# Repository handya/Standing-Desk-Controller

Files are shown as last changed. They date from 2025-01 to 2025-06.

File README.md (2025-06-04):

# Standing Desk Controller (macOS + Arduino)

This repo contains a **macOS test app** and matching **Arduino firmware** to control a custom-built standing desk using serial communication.

Watch the video (https://www.youtube.com/watch?v=RGp0JSYM98Q)

[Find out more on YeahNahDIY.com](https://yeahnahdiy.com/blog/this-standing-desk-was-dumb-so-i-upgraded-it)

⚠️ **This project is experimental and not production ready.** The code is rough and intended for testing purposes only.

---

## 🔌 Arduino Firmware

This firmware runs on an Arduino-compatible board to control the physical desk hardware (motor driver, buttons, rotary encoder).

### Features

* Manual buttons for up/down
* Rotary encoder for height tracking
* 3 preset memory buttons
* EEPROM save/restore of height
* Serial interface for remote commands and status
* Homing support
* Movement timeouts

### Pin Mapping

| Function | Pin |
| --- | --- |
| Rotary A | D3  |
| Rotary B | D2  |
| Button: Down | D4  |
| Button: Up | D5  |
| Button: A | D8  |
| Button: B | D7  |
| Button: C | D6  |
| Motor: Down  | D11 |
| Motor: Up | D12 |

### Serial Protocol (Same as macOS)

* Send `a`, `b`, `c` to go to presets
* Send `s` to stop
* Send a number like `950` to go to that height in mm
* Desk replies with state + height every cycle, e.g.:

  ```
  movingUp
  850
  ```

### Notes

* EEPROM is used to persist height between restarts
* Desk must be **homed** (manually or via `a`/`HOME` button) for presets to work
* Height is calculated using encoder steps with a conversion factor (`heightOffset`)
* All output is in mm

---

## 🛠 Requirements

* Arduino-compatible board (Uno, Nano, etc.)
* Motor driver circuitry
* Rotary encoder (TWO03 latch mode)
* Desk with UP/DOWN inputs
* macOS app built via Xcode
* USB serial connection

---

## 💻 macOS App

### Features

* Control your desk height via a slider
* Three preset position buttons (`a`, `b`, `c`)
* Realtime desk state and height display
* Serial communication via [ORSSerialPort](https://github.com/armadsen/ORSSerialPort)

### Setup

1. Open the project in Xcode.
2. Find your serial port:

   ```swift
   let ports = ORSSerialPortManager.shared().availablePorts
   print(ports)
   ```
3. Update this line in `ViewController.swift` with the correct serial path:

   ```swift
   serialPort = ORSSerialPort(path: "/dev/cu.usbserial-840")!
   ```
4. Build and run.

### Serial Protocol

The macOS app sends the following over serial:

| Action | Serial Output |
| --- | --- |
| Preset 1 | `a\n` |
| Preset 2 | `b\n` |
| Preset 3 | `c\n` |
| Stop Movement | `s\n` |
| Set Height | `950\n` (in mm) |

---

## ⚠️ Disclaimer

This is test software. No safety limits or failsafes are implemented. Use at your own risk.

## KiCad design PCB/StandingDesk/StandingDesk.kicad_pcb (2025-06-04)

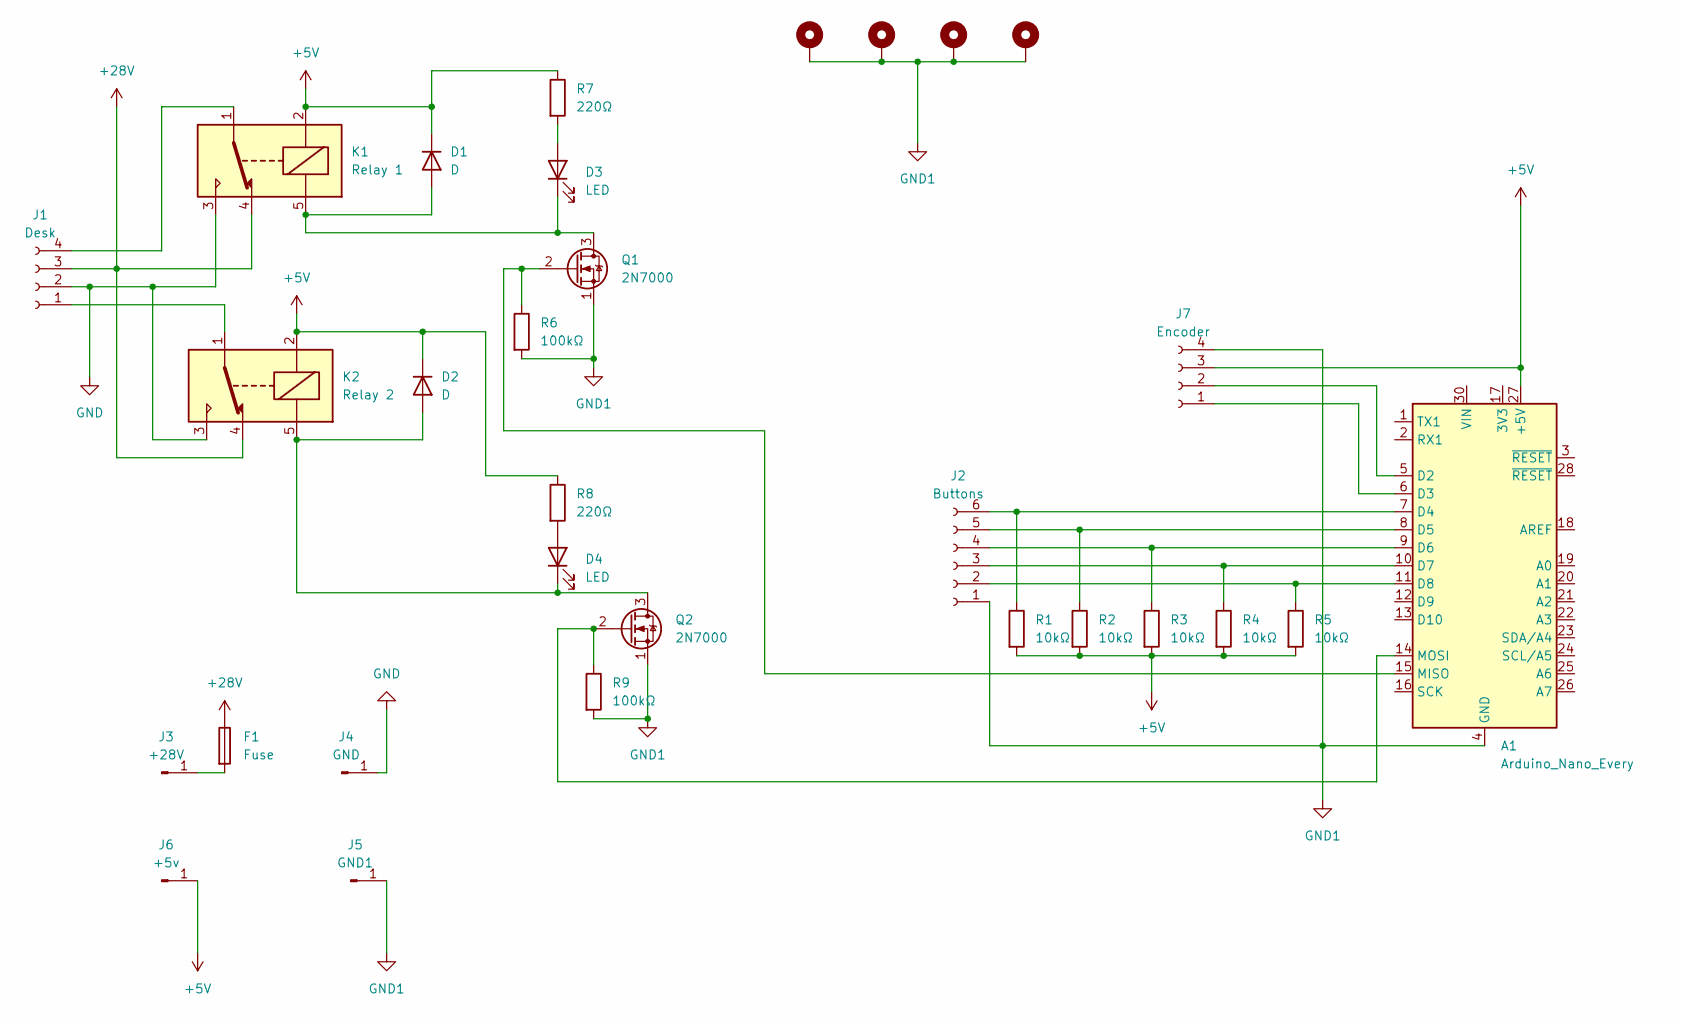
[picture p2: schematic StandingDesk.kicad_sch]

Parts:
A1: Arduino_Nano_Every; Arduino_Nano
D1, D2: D; D_5W_P12.70mm_Horizontal
D3, D4: LED; LED_D3.0mm
F1: Fuse; R_Axial_DIN0207_L6.3mm_D2.5mm_P10.16mm_Horizontal
H1, H2, H3, H4: MountingHole_3mm_Pad
J1: Desk; JST_XH_B4B-XH-A_1x04_P2.50mm_Vertical
J2: Buttons; JST_XH_B6B-XH-A_1x06_P2.50mm_Vertical
J3: +28V; PinHeader_1x01_P2.54mm_Vertical
J4: GND; PinHeader_1x01_P2.54mm_Vertical
J5: GND1; PinHeader_1x01_P2.54mm_Vertical
J6: +5v; PinHeader_1x01_P2.54mm_Vertical
J7: Encoder; JST_XH_B4B-XH-A_1x04_P2.50mm_Vertical
K1: Relay 1; Relay_SPDT_SANYOU_SRD_Series_Form_C
K2: Relay 2; Relay_SPDT_SANYOU_SRD_Series_Form_C
Q1, Q2: 2N7000; TO-92_Inline
R1, R2, R3, R4, R5: 10kΩ; R_Axial_DIN0204_L3.6mm_D1.6mm_P5.08mm_Horizontal
R6, R9: 100kΩ; R_Axial_DIN0204_L3.6mm_D1.6mm_P5.08mm_Horizontal
R7, R8: 220Ω; R_Axial_DIN0204_L3.6mm_D1.6mm_P5.08mm_Horizontal

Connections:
+5V: A1.27 (+5V), D1.1 (K), D2.1 (K), J6.1, J7.3, K1.2, K2.2, R1.2, R2.2, R3.2, R4.2, R5.2, R7.1, R8.1
+28V: F1.1, J1.3, K1.4, K2.4
GND: J1.2, J4.1, K1.3, K2.3
GND1: A1.4 (GND), A1.29 (GND), H1.MP, H2.MP, H3.MP, H4.MP, J2.1, J5.1, J7.4, Q1.1 (S), Q2.1 (S), R6.2, R9.2
unnamed: A1.5 (D2), J7.2
unnamed: A1.6 (D3), J7.1
unnamed: A1.7 (D4), J2.6, R1.1
unnamed: A1.8 (D5), J2.5, R2.1
unnamed: A1.9 (D6), J2.4, R3.1
unnamed: A1.10 (D7), J2.3, R4.1
unnamed: A1.11 (D8), J2.2, R5.1
unnamed: A1.15 (MISO), Q1.2 (G), R6.1
unnamed: A1.14 (MOSI), Q2.2 (G), R9.1
unnamed: D1.2 (A), D3.1 (K), K1.5, Q1.3 (D)
unnamed: D2.2 (A), D4.1 (K), K2.5, Q2.3 (D)
unnamed: D3.2 (A), R7.2
unnamed: D4.2 (A), R8.2
unnamed: J1.1, K2.1
unnamed: J1.4, K1.1
unnamed: F1.2, J3.1

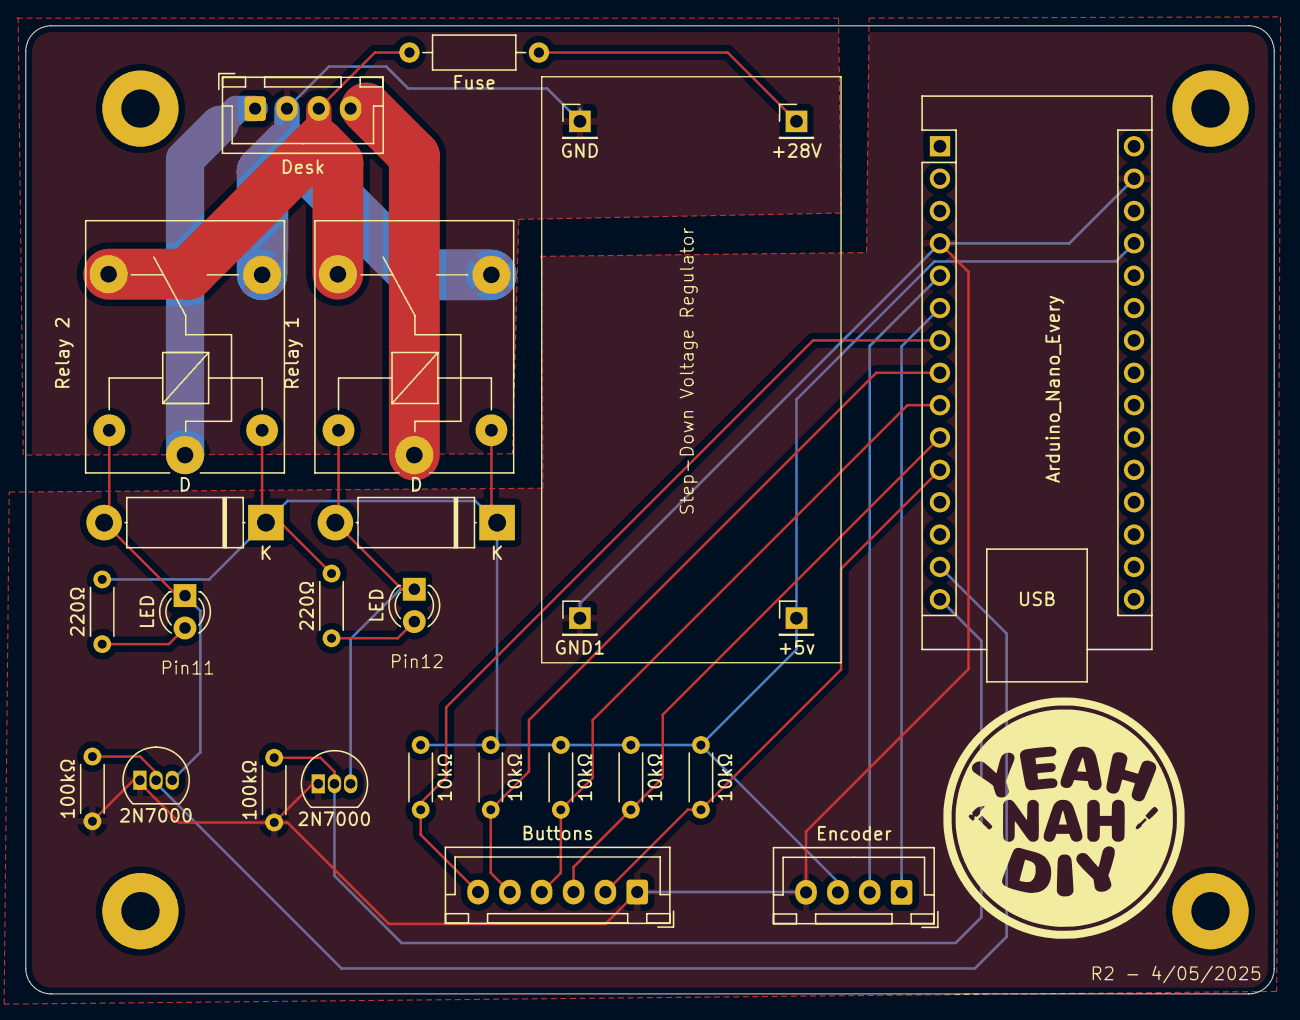
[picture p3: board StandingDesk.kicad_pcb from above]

Board: 2 copper layers, 98.0 x 76.0 mm, 30 parts (0 on the bottom side), 20 nets.

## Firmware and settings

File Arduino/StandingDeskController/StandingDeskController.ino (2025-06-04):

#include <Arduino.h>
#include <RotaryEncoder.h> // by Matthias Hertal
#include <EEPROM.h>

#define SERIAL_BAUD 9600

#define EEPROM_ADDRESS 10
#define EMPTY_VALUE 0xFFFF

enum DeskState {
  IDLE, MOVING_UP, MOVING_DOWN, MANUAL, HOME
};

const char* deskStateToString(DeskState state) {
    switch (state) {
        case IDLE:       return "idle";
        case MOVING_UP:  return "movingUp";
        case MOVING_DOWN:return "movingDown";
        case MANUAL:     return "manual";
        case HOME:       return "home";
        default:         return "unknown";
    }
}

#define PIN_IN1 3
#define PIN_IN2 2

#define PIN_DOWN 11
#define PIN_UP 12

bool downState = HIGH;
bool upState = HIGH;

DeskState deskState = IDLE;

#define PIN_DOWN_BUTTON 4
#define PIN_UP_BUTTON 5

#define PIN_SETTING1_BUTTON 8
#define PIN_SETTING2_BUTTON 7
#define PIN_SETTING3_BUTTON 6

unsigned long lastMovementTime = 0;

float lowestDeskHeight = 700;
float heightOffset = 0.8;

int requestedPos = 0;
int posOne = int(lowestDeskHeight);
int posTwo = 750;
int posThree = 1000;

static int pos = 0;

bool isDeskHomed = false;

// A pointer to the dynamic created rotary encoder instance.
// This will be done in setup()
RotaryEncoder *encoder = nullptr;

void setup() {
  lastMovementTime = millis();
  // Serial.begin(115200);
  // while (!Serial);
  // Serial.println("InterruptRotator example for the RotaryEncoder library.");

  // setup the rotary encoder functionality

  // use FOUR3 mode when PIN_IN1, PIN_IN2 signals are always HIGH in latch position.
  // encoder = new RotaryEncoder(PIN_IN1, PIN_IN2, RotaryEncoder::LatchMode::FOUR3);

  // use FOUR0 mode when PIN_IN1, PIN_IN2 signals are always LOW in latch position.
  // encoder = new RotaryEncoder(PIN_IN1, PIN_IN2, RotaryEncoder::LatchMode::FOUR0);

  // use TWO03 mode when PIN_IN1, PIN_IN2 signals are both LOW or HIGH in latch position.
  encoder = new RotaryEncoder(PIN_IN1, PIN_IN2, RotaryEncoder::LatchMode::TWO03);

  attachInterrupt(digitalPinToInterrupt(PIN_IN1), checkPosition, CHANGE);
  attachInterrupt(digitalPinToInterrupt(PIN_IN2), checkPosition, CHANGE);

  pinMode(PIN_DOWN, OUTPUT);
  pinMode(PIN_UP, OUTPUT);

  pinMode(PIN_DOWN_BUTTON, INPUT);
  pinMode(PIN_UP_BUTTON, INPUT);
  pinMode(PIN_SETTING1_BUTTON, INPUT);
  pinMode(PIN_SETTING2_BUTTON, INPUT);
  pinMode(PIN_SETTING3_BUTTON, INPUT);

  digitalWrite(PIN_DOWN, !downState);
  digitalWrite(PIN_UP, !upState);

  Serial.begin(SERIAL_BAUD); 

  int storedValue = loadFromEEPROM();
  if (storedValue == -1) {
    isDeskHomed = false;
  } else {
    isDeskHomed = true;
    pos = storedValue;
    encoder->setPosition(storedValue);
  }
} 

void loop() {
  encoder->tick();

  int newPos = encoder->getPosition();
  if (pos != newPos) {
    pos = newPos;
    lastMovementTime = millis();
  }

  int downSwitch = digitalRead(PIN_DOWN_BUTTON);
  int upSwitch = digitalRead(PIN_UP_BUTTON);
  int setting1Switch = digitalRead(PIN_SETTING1_BUTTON);
  int setting2Switch = digitalRead(PIN_SETTING2_BUTTON);
  int setting3Switch = digitalRead(PIN_SETTING3_BUTTON);

  if (downSwitch == 0) {
    deskState = MANUAL;
    setDownState(LOW);
    setUpState(HIGH);
  } else if (upSwitch == 0) {
    setDownState(HIGH);
    setUpState(LOW);
    deskState = MANUAL;
  } else if (deskState == MANUAL) {
    setDownState(HIGH);
    setUpState(HIGH);
    deskState = IDLE;
    saveToEEPROM(pos);
  }

  if (setting1Switch == 0) {
    deskState = HOME;
    lastMovementTime = millis();
    // goToPos(posOne, newPos);
  }

  if (setting2Switch == 0) {
    goToPos(posTwo, newPos);
  }

  if (setting3Switch == 0) {
     goToPos(posThree, newPos);
  }

  checkSerial(newPos);

  switch (deskState) {
    case IDLE:
      break;
    case MOVING_UP:
      if (downState == LOW) {
        setDownState(HIGH);
      }
      if (newPos < requestedPos) {
        setUpState(LOW);
      } else if (newPos >= requestedPos) {
        setUpState(HIGH);
        deskState = IDLE;
        saveToEEPROM(pos);
      }
      checkForMovement();
      break;
    case MOVING_DOWN:
      if (upState == LOW) {
        setUpState(HIGH);
      }
      if (newPos > requestedPos) {
        setDownState(LOW);
      } else if (newPos <= requestedPos) {
        setDownState(HIGH);
        deskState = IDLE;
        saveToEEPROM(pos);
      }
      checkForMovement();
      break;
    case MANUAL:
      checkForMovement();
      break;
    case HOME:
      if (downState == HIGH) {
        setDownState(LOW);
        setUpState(HIGH);
      }
      checkForMovement();
      break;
  }

  if (isDeskHomed) {
    Serial.println(deskStateToString(deskState));
    int mmPos = (pos * heightOffset) + lowestDeskHeight;
    Serial.println(mmPos);
  } else {
    Serial.println("unhomed");
  }
}

// new pos in mm, and current pos in steps
void goToPos(int mmPos, int currentPos) {
    if (!isDeskHomed) {
      return;
    }

    // convert mm to step count
    requestedPos = int((mmPos - lowestDeskHeight) / heightOffset);

    if (currentPos > requestedPos) {
      if (deskState == MOVING_UP) {
        deskState = IDLE;
        saveToEEPROM(pos);
      } else {
        deskState = MOVING_DOWN;
      }
      lastMovementTime = millis();
    } else if (currentPos < requestedPos) {
      if (deskState == MOVING_DOWN) {
        deskState = IDLE;
        saveToEEPROM(pos);
      } else {
        deskState = MOVING_UP;
      }
      lastMovementTime = millis();
    }
}

void checkForMovement() {
  // turn off if no movemnt detected
  if (millis() - lastMovementTime > 1000 && (downState == LOW || upState == LOW)) {
    setDownState(HIGH);
    setUpState(HIGH);
    if (deskState == HOME) {
      encoder->setPosition(0);
      isDeskHomed = true;
    }
    deskState = IDLE;
    lastMovementTime = millis();
    saveToEEPROM(pos);
  }
}

void checkPosition() {
  encoder->tick(); // just call tick() to check the state.
}

void setDownState(bool state) {
  if (downState != state) {
    downState = state;
    digitalWrite(PIN_DOWN, !downState);
  }
}

void setUpState(bool state) {
  if (upState != state) {
    upState = state;
    digitalWrite(PIN_UP, !upState);
  }
}

void checkSerial(int currentPos) {
      if (Serial.available()) {
        String input = Serial.readStringUntil('\n'); // Read the input until newline
        input.trim(); // Remove leading and trailing spaces

        if (input.length() == 1 && isAlpha(input[0])) {
            // If input is a single letter (a-z), trigger corresponding function
              handleLetter(input[0], currentPos);
        } else if (isNumeric(input)) {

            // If input is a number (0-9999), update state
            int number = input.toInt();
            if (number >= 0 && number <= 9999 && number >= lowestDeskHeight) {
              goToPos(number, currentPos);
            }
        }
    }
}

void handleLetter(char letter, int currentPos) {
    switch (letter) {
        case 'a': 
        Serial.println("Action A triggered!"); 
        deskState = HOME;
        lastMovementTime = millis();
        break;
        case 'b': 
        Serial.println("Action B triggered!"); 
        goToPos(posTwo, currentPos);
        break;
        case 'c': 
        Serial.println("Action B triggered!"); 
        goToPos(posThree, currentPos);
        break;

        case 's': // stop
        lastMovementTime = 0;
        break;

        default: 
        break;
    }
}

bool isNumeric(String str) {
    for (int i = 0; i < str.length(); i++) {
        if (!isDigit(str[i])) return false;
    }
    return true;
}

void saveToEEPROM(int value) {
    EEPROM.put(EEPROM_ADDRESS, value);
}

int loadFromEEPROM() {
    int value;
    EEPROM.get(EEPROM_ADDRESS, value);

    // Check if the read value is uninitialized (all bytes set to 0xFF)
    if (value == EMPTY_VALUE) {
        Serial.println("No valid data found in EEPROM.");
        return -1;  // Return a default value or handle accordingly
    }
    return value;
}

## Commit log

2025-06-04 feat: add Arduino code
2025-06-04 feat: add pcb
    [StandingDesk.kicad_pcb, StandingDesk.kicad_sch]
